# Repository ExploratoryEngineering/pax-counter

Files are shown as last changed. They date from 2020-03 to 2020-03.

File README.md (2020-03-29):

# PAX Counter

This device scans for visible bluetooth and wifi devices and then transmits the device count over NBIoT to a backend server.

Tested on a ESP-WROOM-32D + [EE-NBIoT-01](https://github.com/ExploratoryEngineering/ee-nbiot-01) rat's nest ;)

## Wiring (ESP):
* VCC   3.3V
* EN    to VCC via 10k pull-up
* IO0   to GND via boot switch (enable programming mode by grounding IO0 before power-on)
* GND
* IO16    to EE-NBIoT-01 RXD
* IO17    to EE-NBIoT-01 TXD
* RXD0    a) to FTDI TX and b) to GND via 10k pull-down
* TXD0    to FTDI RX

1) Use common ground for ESP-WROOM-32D, EE-NBIoT-01 and FTDI.
2) Leave FTDI VCC pin unconnected

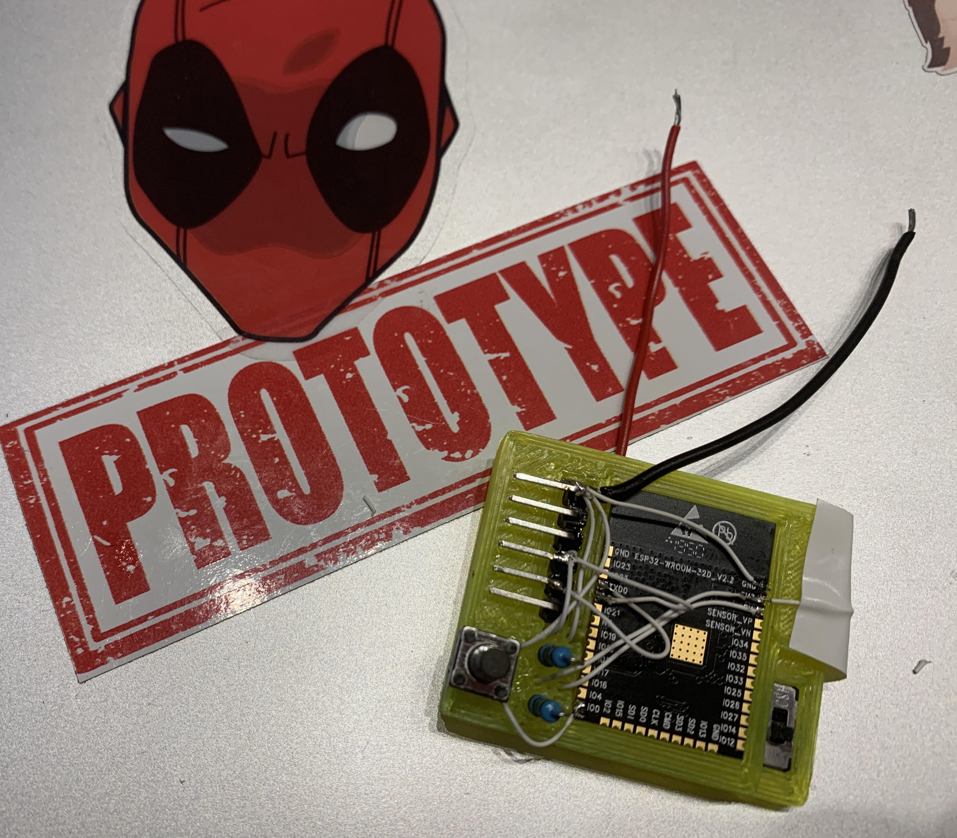
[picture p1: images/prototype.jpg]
Prototype


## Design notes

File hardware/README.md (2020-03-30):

# mikroBUS PAX Counter

(Work in progress)

## BoM
* ESP-WROOM-32D
* PTS645 SMT switch
* 2 x 0402 10k resistor
* 1 x 6 pin 2.54mm pin header
* 2 x 8 pin 2.54mm pin header

[mikroBUS specification](https://download.mikroe.com/documents/standards/mikrobus/mikrobus-standard-specification-v200.pdf)

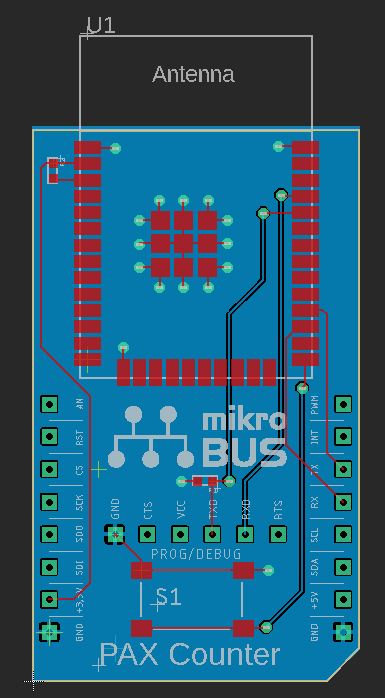
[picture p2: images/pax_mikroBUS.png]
Eagle board


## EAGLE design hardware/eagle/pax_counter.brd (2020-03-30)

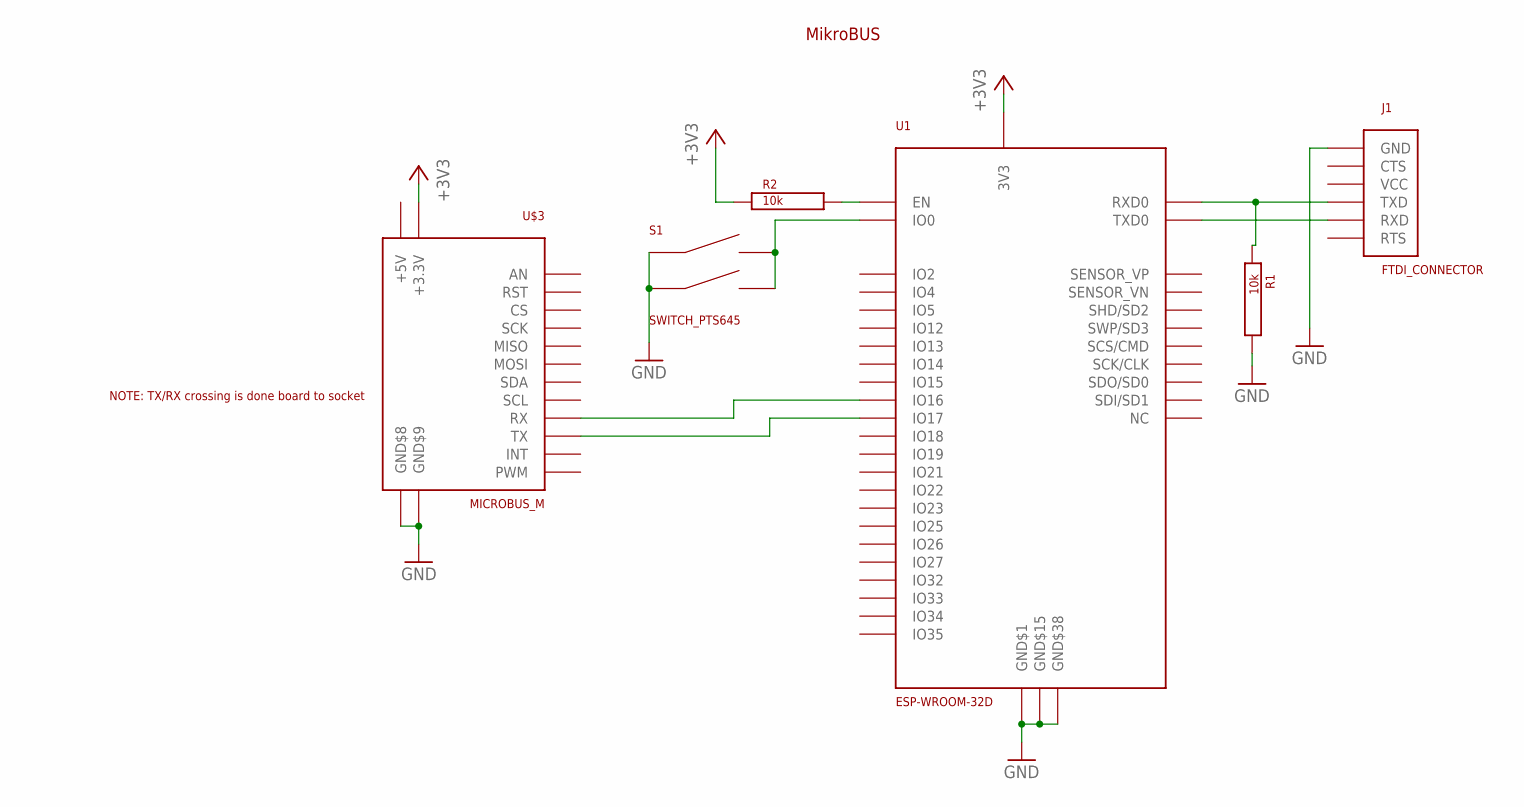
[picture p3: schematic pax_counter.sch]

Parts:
J1: FTDI_CONNECTOR
R1, R2: 10k; RES_0402
S1: SWITCH_PTS645; SWITCH_PTS645_EE_NBIOT_01
U1: ESP-WROOM-32D; ESP_WROOM_32D
U$1: MIKROBUS_LOGO
U$3: MICROBUS_M; MIKROBUS_M

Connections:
+3V3: R2.P$1, U1.2 (3V3), U$3.+3.3V
GND: J1.GND, R1.P$2, S1.A1, S1.A2, U1.1 (GND$1), U1.15 (GND$15), U1.38 (GND$38), U1.GND$39 (GND$38), U1.GND$40 (GND$38), U1.GND$41 (GND$38), U1.GND$42 (GND$38), U1.GND$43 (GND$38), U1.GND$44 (GND$38), U1.GND$45 (GND$38), U1.GND$46 (GND$38), U1.GND$47 (GND$38), U$3.GND$8, U$3.GND$9
unnamed: U1.27 (IO16), U$3.RX
unnamed: U1.28 (IO17), U$3.TX
unnamed: R2.P$2, U1.3 (EN)
unnamed: J1.TXD, R1.P$1, U1.34 (RXD0)
unnamed: J1.RXD, U1.35 (TXD0)
unnamed: S1.B1, S1.B2, U1.25 (IO0)

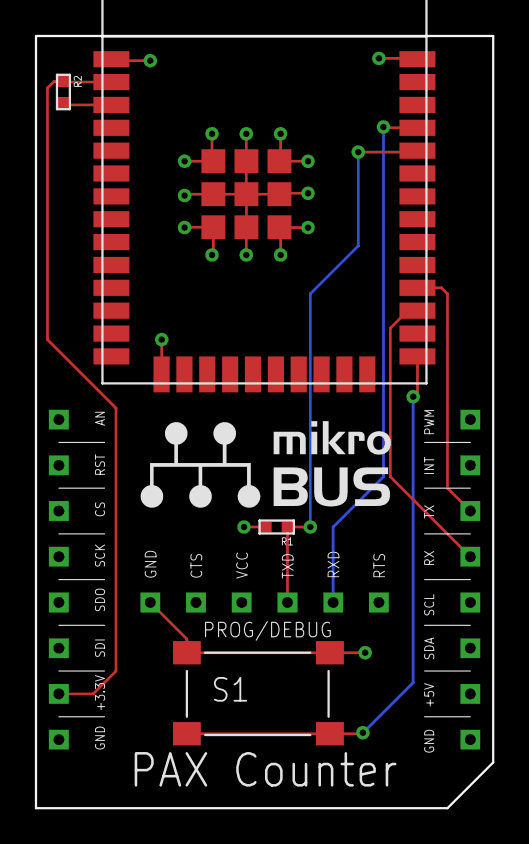
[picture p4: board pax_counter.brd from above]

Board: 2 copper layers, 25.4 x 42.9 mm, 7 parts (0 on the bottom side), 8 nets.

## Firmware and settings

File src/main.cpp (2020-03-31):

#include <Arduino.h>

#include "TelenorNBIot.h"
#include "wifi_scan.h"
#include "ble_scan.h"
#include "mac_pool.h"

MACAddressPool pool(300000); // Age limit: 5 minutes

void setup() 
{
  wifi_scanner_setup();
  ble_scanner_setup();
  nbiot_setup();
  Serial.begin(115200);
 }

void loop() 
{
  while (true)
  {
    wifi_scan();
    ble_scan();
    nbiot_transmit_message(pool.get_count(BT), pool.get_count(WIFI));
    pool.Purge();
    pool.Log();
  }
}

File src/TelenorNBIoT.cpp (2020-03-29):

/*
   Copyright 2018 Telenor Digital AS

   Licensed under the Apache License, Version 2.0 (the "License");
   you may not use this file except in compliance with the License.
   You may obtain a copy of the License at

       http://www.apache.org/licenses/LICENSE-2.0

   Unless required by applicable law or agreed to in writing, software
   distributed under the License is distributed on an "AS IS" BASIS,
   WITHOUT WARRANTIES OR CONDITIONS OF ANY KIND, either express or implied.
   See the License for the specific language governing permissions and
   limitations under the License.
*/
#include <Arduino.h>
#include "func.h"
#include "TelenorNBIoT.h"
#include <Udp.h>

#define PREFIX "AT+"
#define POSTFIX "\r"
#define SOCR "NSOCR=\"DGRAM\",17,%d,1"
#define SOSTF "NSOSTF="
#define SOCL "NSOCL=%d"
#define RECVFROM "NSORF=%d,%d"
#define GPRS "CGATT?"
#define REG_STATUS "CEREG?"
#define IMSI "CIMI"
#define IMEI "CGSN=1"
#define REBOOT "NRB"
#define RADIO_ON "CFUN=1"
#define RADIO_OFF "CFUN=0"
#define SIGNAL_STRENGTH "CSQ"
#define CONNECT_DATA "CGATT=1"
#define FIRMWARE "CGMR"
#define READ_APN "CGDCONT?"
#define SET_APN "CGDCONT=%d,\"IP\",\"%s\""
#define ACTIVATE_APN "CGACT=1,%d"
#define CONFIG_AUTOCONN "NCONFIG=\"AUTOCONNECT\",\"%s\""
#define DEFAULT_TIMEOUT 2000

int splitFields(char *line, char **fields, uint8_t maxFields);
bool retry(uint8_t attempts, nonstd::function<bool ()> fn, uint16_t delayBetween = 100);

TelenorNBIoT::TelenorNBIoT(String accessPointName, uint16_t mobileCountryCode, uint16_t mobileNetworkCode)
{
    _socket = -1;
    memset(_imei, 0, 16);
    memset(_imsi, 0, 16);

    mcc = mobileCountryCode;
    mnc = mobileNetworkCode;
    strcpy(apn, accessPointName.c_str());
}

bool TelenorNBIoT::begin(Stream &serial, bool _debug)
{
    debug = _debug;
    if (debug) {
        Serial.println("NB-IoT debug enabled");
    }
    //Stream &serial
    ublox = &serial;
    // Increase timeout for the module. It might be slow to respond on certain
    // commands.
    ublox->setTimeout(DEFAULT_TIMEOUT);
    while (!ublox) {}
    drain();
    setAutoConnect(false);
    reboot();

    return online() &&
        setNetworkOperator(mcc, mnc) &&
        ensureAccessPointName(apn);
}

bool TelenorNBIoT::enableErrorCodes()
{
    // Enable error codes for u-blox SARA N2 errors
    return retry(10, [this]() {
        writeCommand("CMEE=1");
        return readCommand(lines) == 1 && isOK(lines[0]);
    });
}

bool TelenorNBIoT::setNetworkOperator(uint8_t mobileCountryCode, uint8_t mobileNetworkCode)
{
    if (mobileCountryCode > 0 && mobileNetworkCode > 0) {
        char buffer[40];
        sprintf(buffer, "COPS=1,2,\"%d%02d\"", mobileCountryCode, mobileNetworkCode);
        writeCommand(buffer);
    } else {
        writeCommand("COPS=0");
    }
    return readCommand(lines) == 1 && isOK(lines[0]);
}

bool TelenorNBIoT::ensureAccessPointName(const char *accessPointName)
{
    char *currentAPN = readAccessPointName();
    if (currentAPN != NULL && strcmp(currentAPN, accessPointName) == 0)
    {
        return true;
    }
    return setAccessPointName(accessPointName);
}

char* TelenorNBIoT::readAccessPointName()
{
    writeCommand(READ_APN);
    int count = readCommand(lines);
    if (!isOK(lines[count-1]))
    {
        return NULL;
    }

    // We only care about context ID 0, but the contexts might be out of order,
    // so we have too loop through all to make sure we find it.
    for (uint8_t i=0; i<count-1; i++)
    {
        // +CGDCONT: 0,"IP","mda.ee",,0,0,,,,,1
        char* fields[3];
        if (splitFields(lines[i] + 10, fields, 3) >=3)
        {
            int contextId = atoi(fields[0]);
            char* apn = fields[2];
            
            if (contextId == 0)
            {
                return apn;
            }
        }
    }

    return NULL;
}

bool TelenorNBIoT::setAccessPointName(const char *accessPointName)
{
    if (strlen(accessPointName) == 0)
    {
        // If the APN is blank, don't override the network default PDP context
        return true;
    }

    return retry(3, [this, accessPointName]() {
        sprintf(buffer, SET_APN, 0, accessPointName);
        writeCommand(buffer);
        return readCommand(lines) == 1 && isOK(lines[0]);
    });
}

bool TelenorNBIoT::setAutoConnect(bool enabled)
{
    sprintf(buffer, CONFIG_AUTOCONN, enabled ? "TRUE" : "FALSE");
    writeCommand(buffer);
    return readCommand(lines) == 1 && isOK(lines[0]);
}

bool TelenorNBIoT::dataOn()
{
    writeCommand(CONNECT_DATA);
    if (readCommand(lines) == 1 && isOK(lines[0]))
    {
        return true;
    }
    return false;
}

bool TelenorNBIoT::isConnected()
{
    writeCommand(GPRS);
    if (readCommand(lines) == 2 && isOK(lines[1]))
    {
        // Line contains "+CGATT: <1:available, 0:not available"
        // The GPRS status isn't strictly the online/offline indicator but
        // reasonable close. It will be available if the module is online
        return (*(lines[0] + 8) == '1');
    }
    return false;
}

TelenorNBIoT::registrationStatus_t TelenorNBIoT::registrationStatus()
{
    int statusNum = -1;
    writeCommand(REG_STATUS);
    if (readCommand(lines) == 2 && isOK(lines[1]))
    {
        // Line contains "+CEREG: <n>,<status>"
        statusNum = atoi((lines[0] + 10));
    }
    
    if (statusNum == 0) {
        return RS_NOT_REGISTERED;
    } else if (statusNum == 1) {
        return RS_REGISTERED;
    } else if (statusNum == 2) {
        return RS_REGISTERING;
    } else if (statusNum == 3) {
        return RS_DENIED;
    }
    return RS_UNKNOWN;
}

bool TelenorNBIoT::isRegistered()
{
    return registrationStatus() == RS_REGISTERED;
}

bool TelenorNBIoT::isRegistering()
{
    return registrationStatus() == RS_REGISTERING;
}

String TelenorNBIoT::imei()
{
    if (strnlen(_imei, sizeof _imei) != 15)
    {
        retry(10, [this]() {
            writeCommand(IMEI);
            if (readCommand(lines) == 2 && isOK(lines[1]))
            {
                // Line 1 contains IMEI ("+CGSN: <15-digit IMEI>")
                char *ptr = lines[0] + 7;
                if (strnlen(ptr, 16) == 15) {
                    memcpy(_imei, ptr, 16);
                    return true;
                }
            }
            
            return false;
        });
    }
    return String(_imei);
}

String TelenorNBIoT::imsi()
{
    if (strnlen(_imsi, sizeof _imsi) != 15)
    {
        retry(10, [this]() {
            writeCommand(IMSI);
            if (readCommand(lines) == 2 && isOK(lines[1]) && strnlen(lines[0], 16) == 15)
            {
                // Line contains IMSI ("<15 digit IMSI>")
                memcpy(_imsi, lines[0], strnlen(lines[0], 15) + 1);
                return true;
            }
            return false;
        });
    }
    return String(_imsi);
}
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

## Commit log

2020-03-29 Added wiring description
2020-03-29 Moved wiring desc to readme
2020-03-29 Added device image
2020-03-30 Added mikroBUS HW design
    [pax_counter.brd, pax_counter.sch]
2020-03-30 Added Eagle snapshot of board
2020-03-31 Added missing function prototypes
